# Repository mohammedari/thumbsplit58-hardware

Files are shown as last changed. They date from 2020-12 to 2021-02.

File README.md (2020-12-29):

# Thumbsplit58 Hardware
File archive for Thumbsplit58 keyboard PCB and case. You may also want to refer [Nordic MCU firmware](https://github.com/mohammedari/thumbsplit58-firmware) and [qmk_firmware](https://github.com/mohammedari/qmk_firmware/blob/oneoff/thumbsplit58/keyboards/thumbsplit58/) repository.

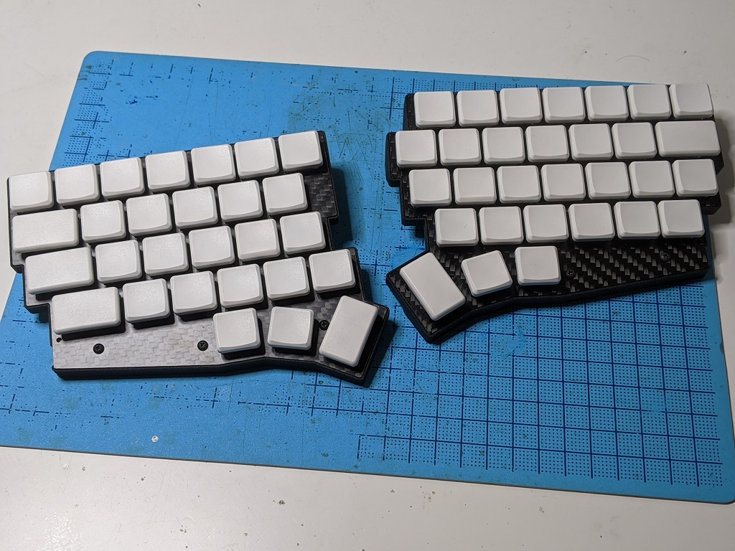
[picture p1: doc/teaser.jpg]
teaser


This repository only contains PCB gerber files for keyboard itself. 
You can use [Comet46's receiver gerber files](https://github.com/satt100/comet46-hardware.git) to make receiver for this keyboard.

## Top plates

Top plate DXF files are available under [dxf](dxf) directory.
This design is intended to be milled using 2mm endmill, 
but it should be manufacturable by laser cutters.

| | Left | Right |
| --- | --- | --- |
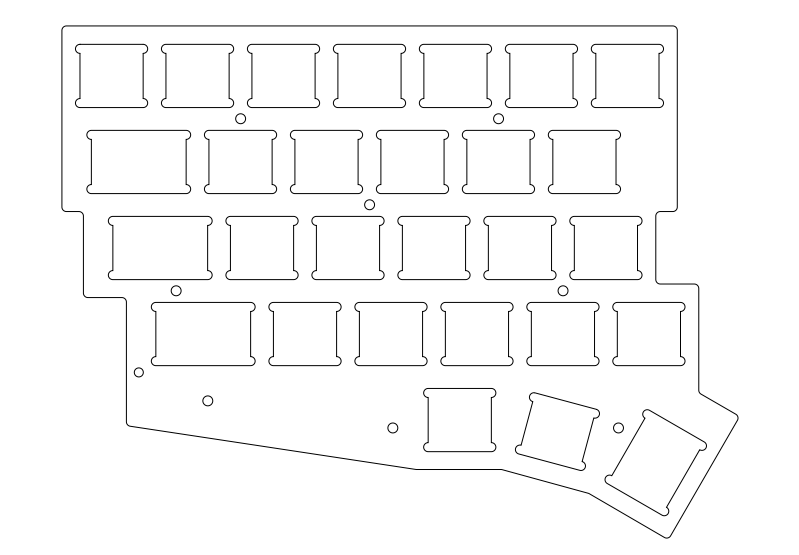
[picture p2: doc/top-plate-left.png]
left
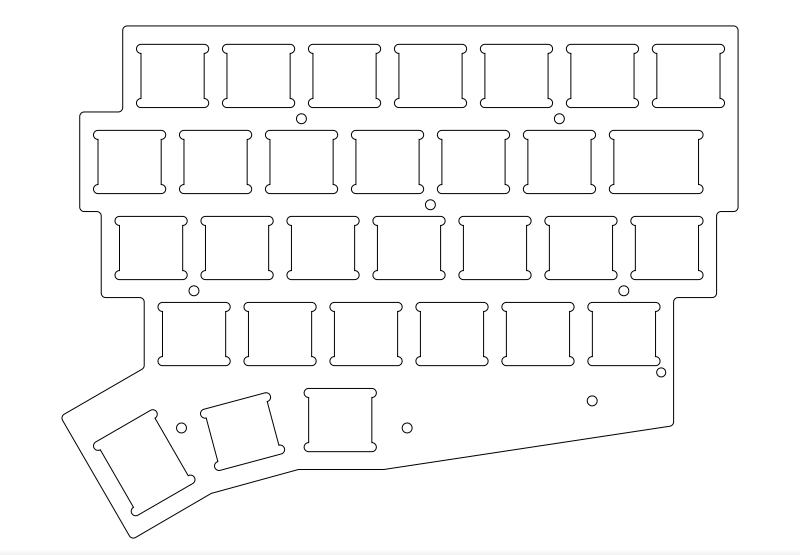
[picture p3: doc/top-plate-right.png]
right
| rev1 (1u/1.5u support) |  |  |
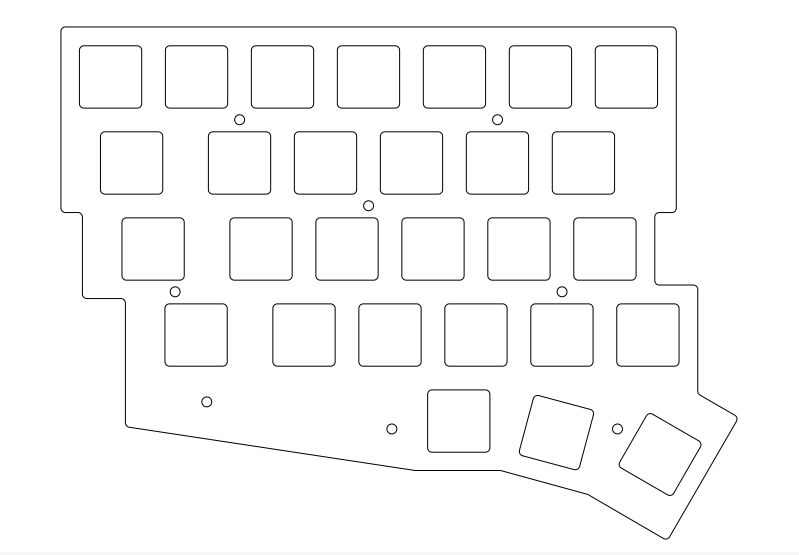
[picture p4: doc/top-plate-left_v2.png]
leftv2
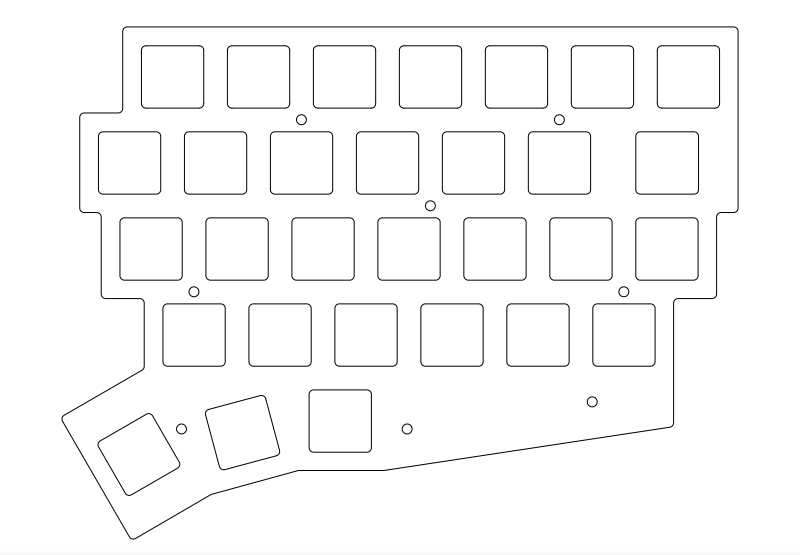
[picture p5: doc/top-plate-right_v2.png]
rightv2
| rev2 (1.5u only) |  |  |

## Case

Case STL files are available under [stl](stl) directory.
This design is intended to be 3D printed using SLS (Selective Laser Sintering) or SLA (Stereolithography) printer.
It may be printable by FDM (Fused Deposition Modeling) printers, but probably requires additional work.

| | Left | Right |
| --- | --- | --- |
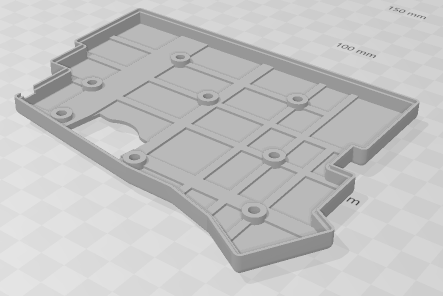
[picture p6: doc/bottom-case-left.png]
left
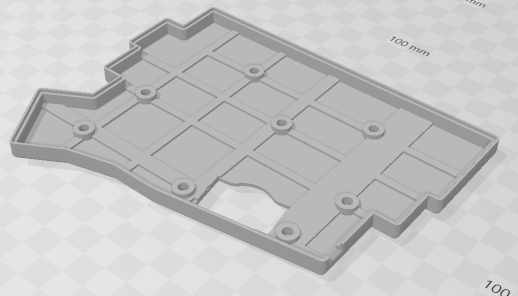
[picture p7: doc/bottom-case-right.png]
right
| rev1 (CR2032) |  |  |
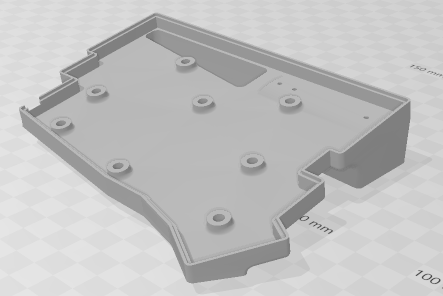
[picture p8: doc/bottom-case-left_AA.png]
leftAA
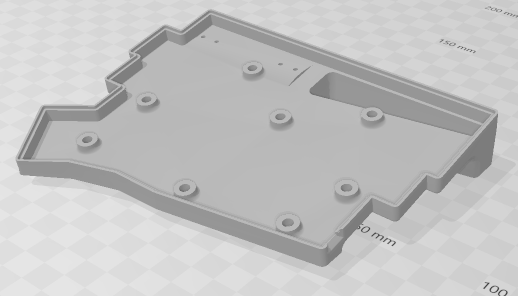
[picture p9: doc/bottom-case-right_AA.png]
rightAA
| rev2 (AA) |  |  |

## Gerber files

Gerber files are available under [gerber](gerber) directory. 
These archives follow Fusion PCB's design guideline and output instruction.

## Schematics

- [Right half](schematic/thumb-split-right-v1.0.pdf)
- [Left half](schematic/thumb-split-left-v1.0.pdf)

## Parts list

TODO

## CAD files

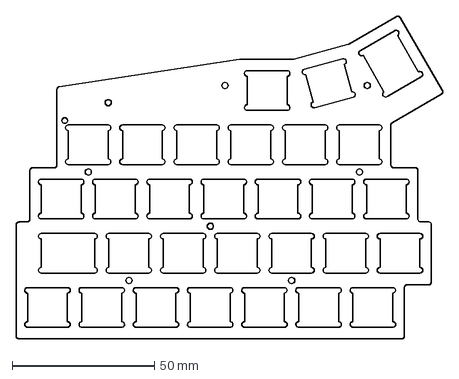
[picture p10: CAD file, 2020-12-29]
dxf/top-plate-right.dxf
149.8 x 113.4 mm

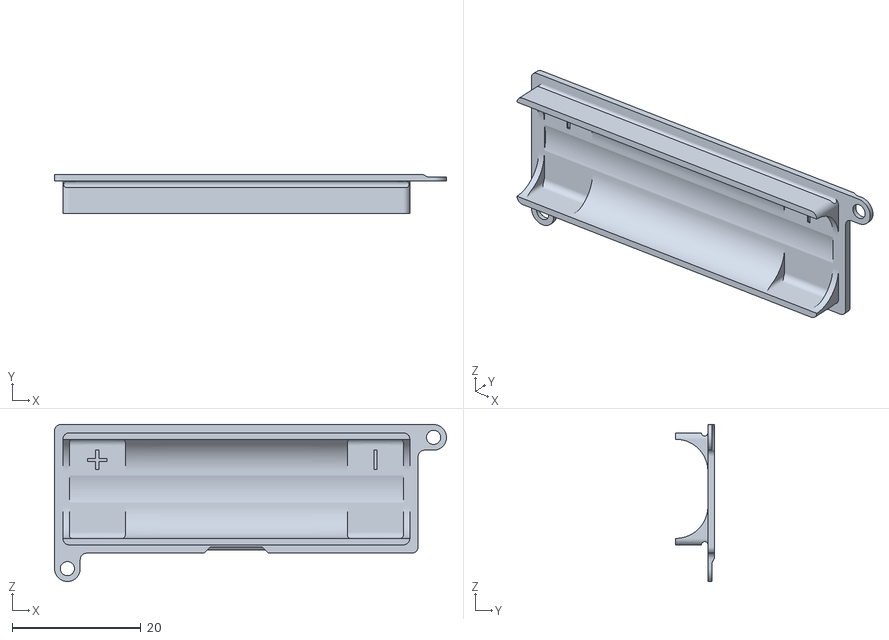
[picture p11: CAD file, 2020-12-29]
stl/battery-cover-right_v2.stl
60.9 x 6.00 x 24.4

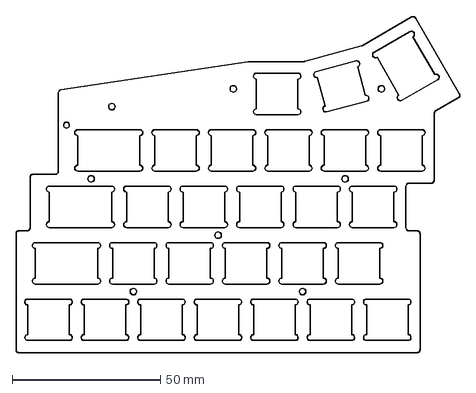
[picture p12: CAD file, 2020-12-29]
dxf/top-plate-left.dxf
149.8 x 113.4 mm

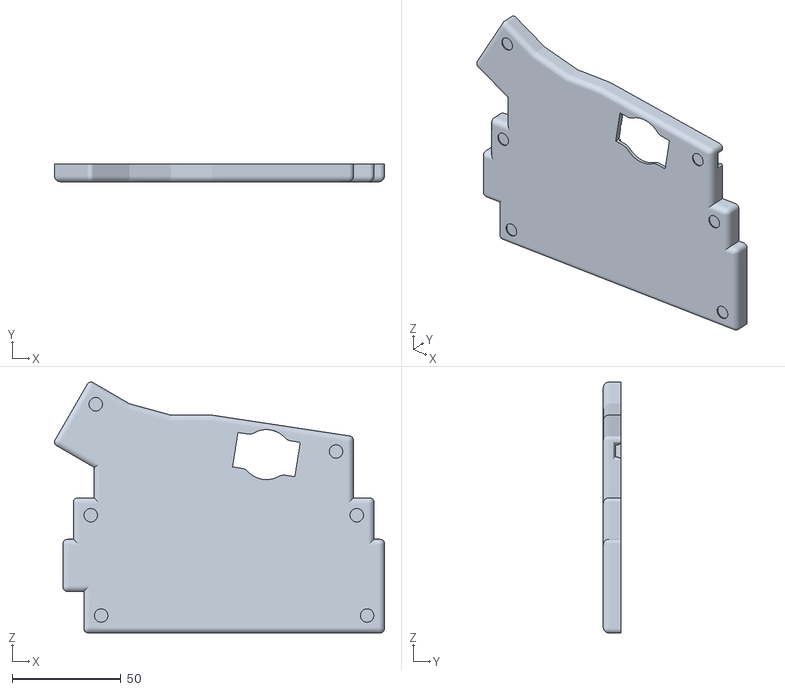
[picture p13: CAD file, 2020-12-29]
stl/bottom-case-right.stl
151.8 x 8.10 x 115.4

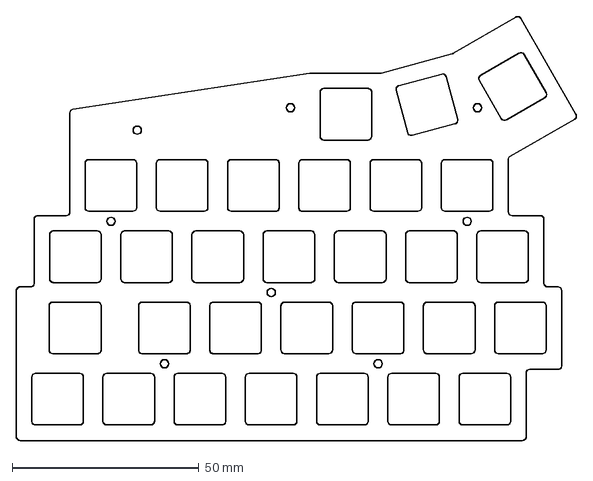
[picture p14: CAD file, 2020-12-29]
dxf/top-plate-right_v2.dxf
149.8 x 113.4 mm

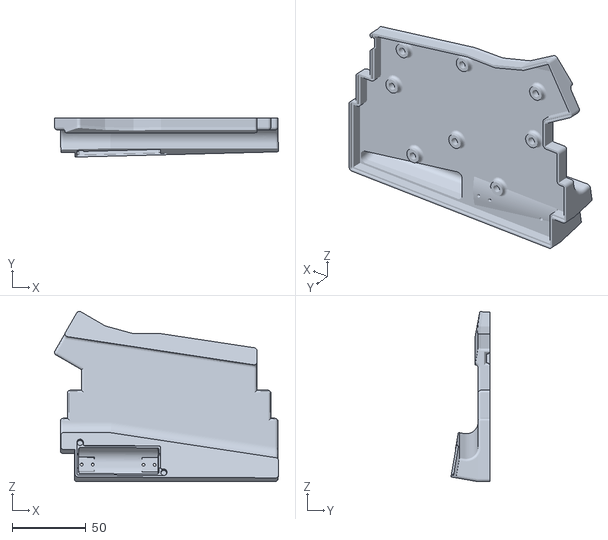
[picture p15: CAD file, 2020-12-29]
stl/bottom-case_AA-right.stl
152.2 x 26.5 x 115.7

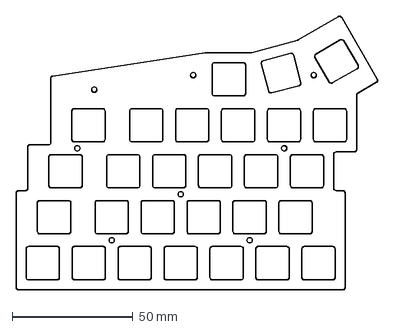
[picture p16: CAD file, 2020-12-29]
dxf/top-plate-left_v2.dxf
149.8 x 113.4 mm

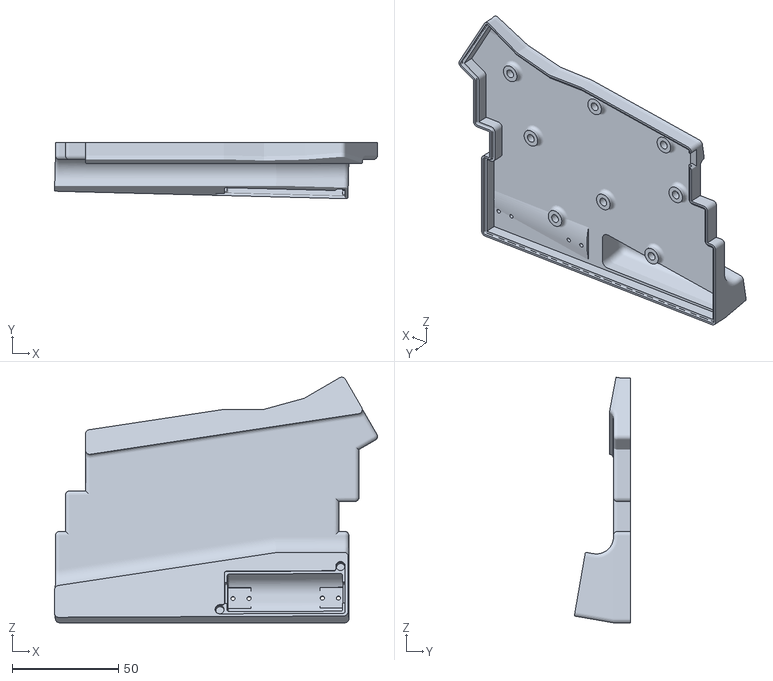
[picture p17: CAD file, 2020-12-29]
stl/bottom-case_AA-left.stl
152.2 x 26.5 x 115.7

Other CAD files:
stl/bottom-case-left.stl
stl/battery-cover-left_v2.stl

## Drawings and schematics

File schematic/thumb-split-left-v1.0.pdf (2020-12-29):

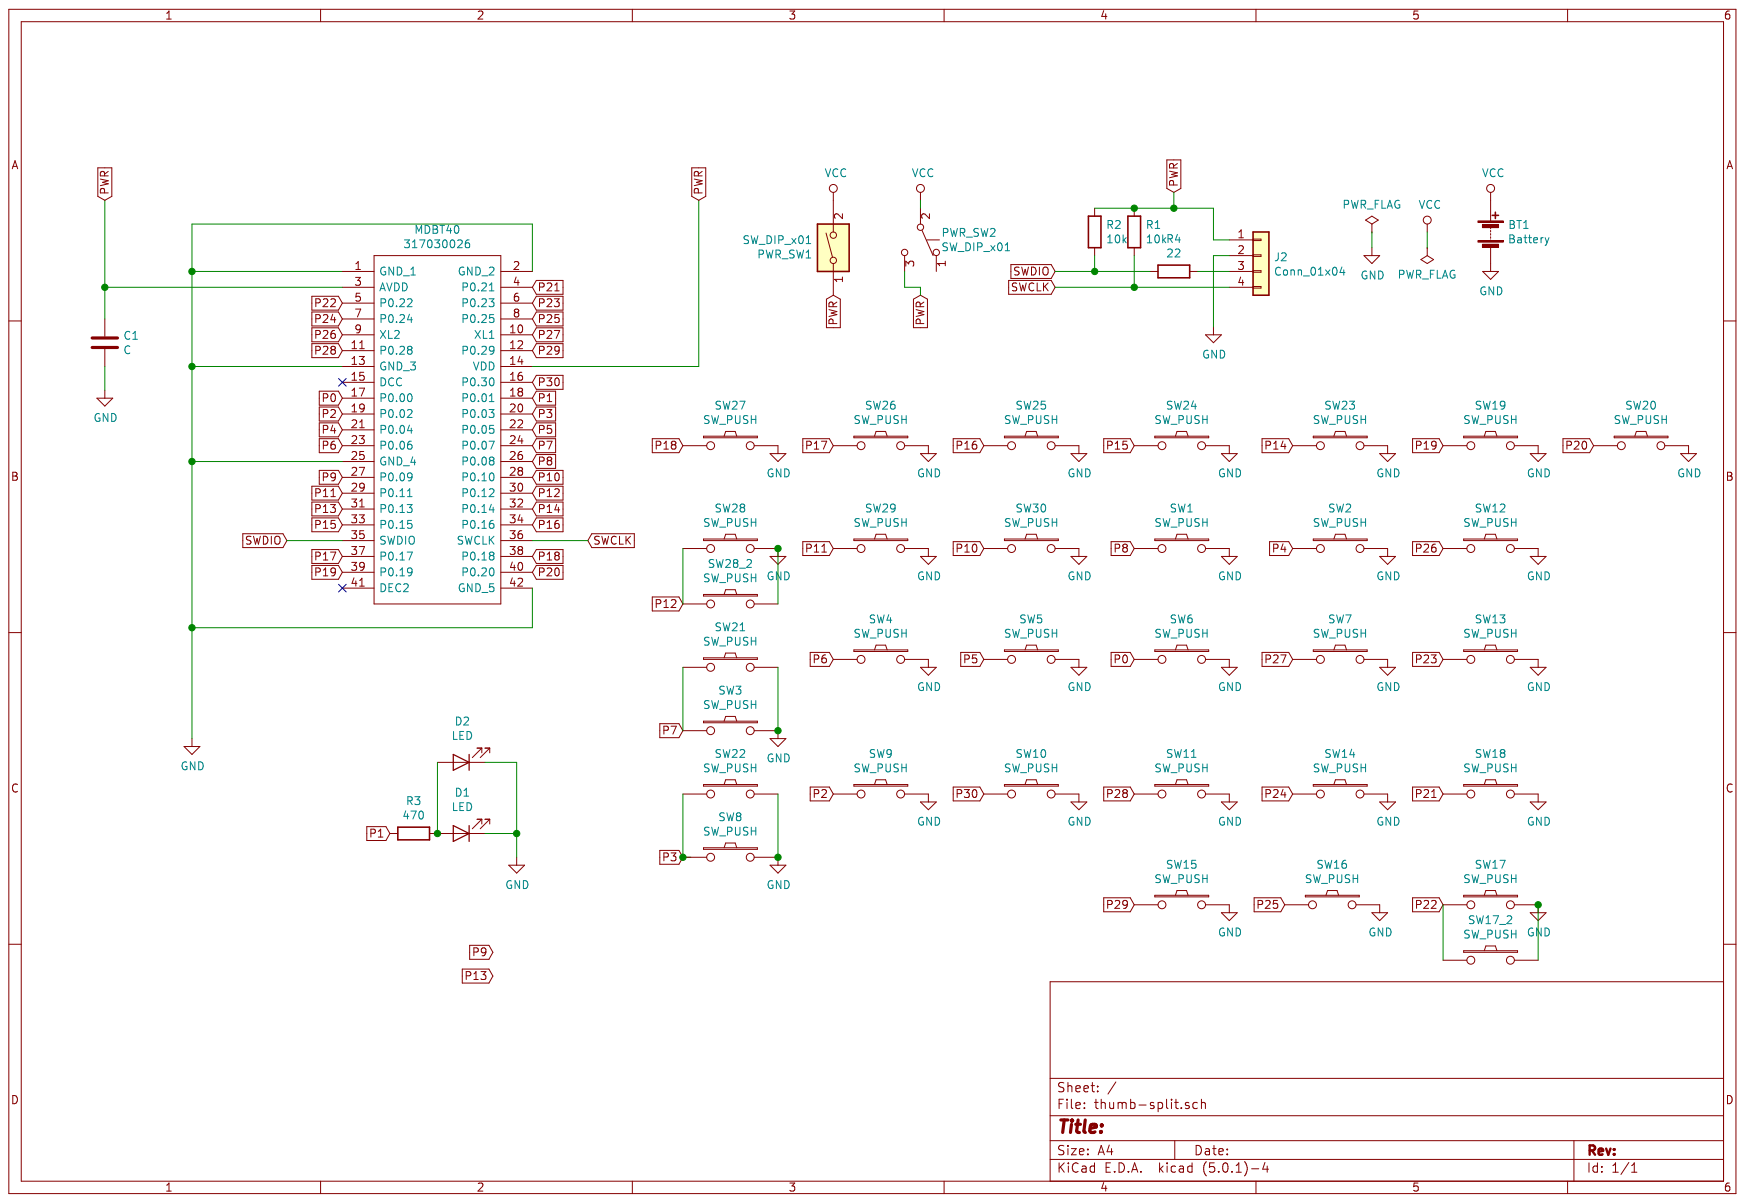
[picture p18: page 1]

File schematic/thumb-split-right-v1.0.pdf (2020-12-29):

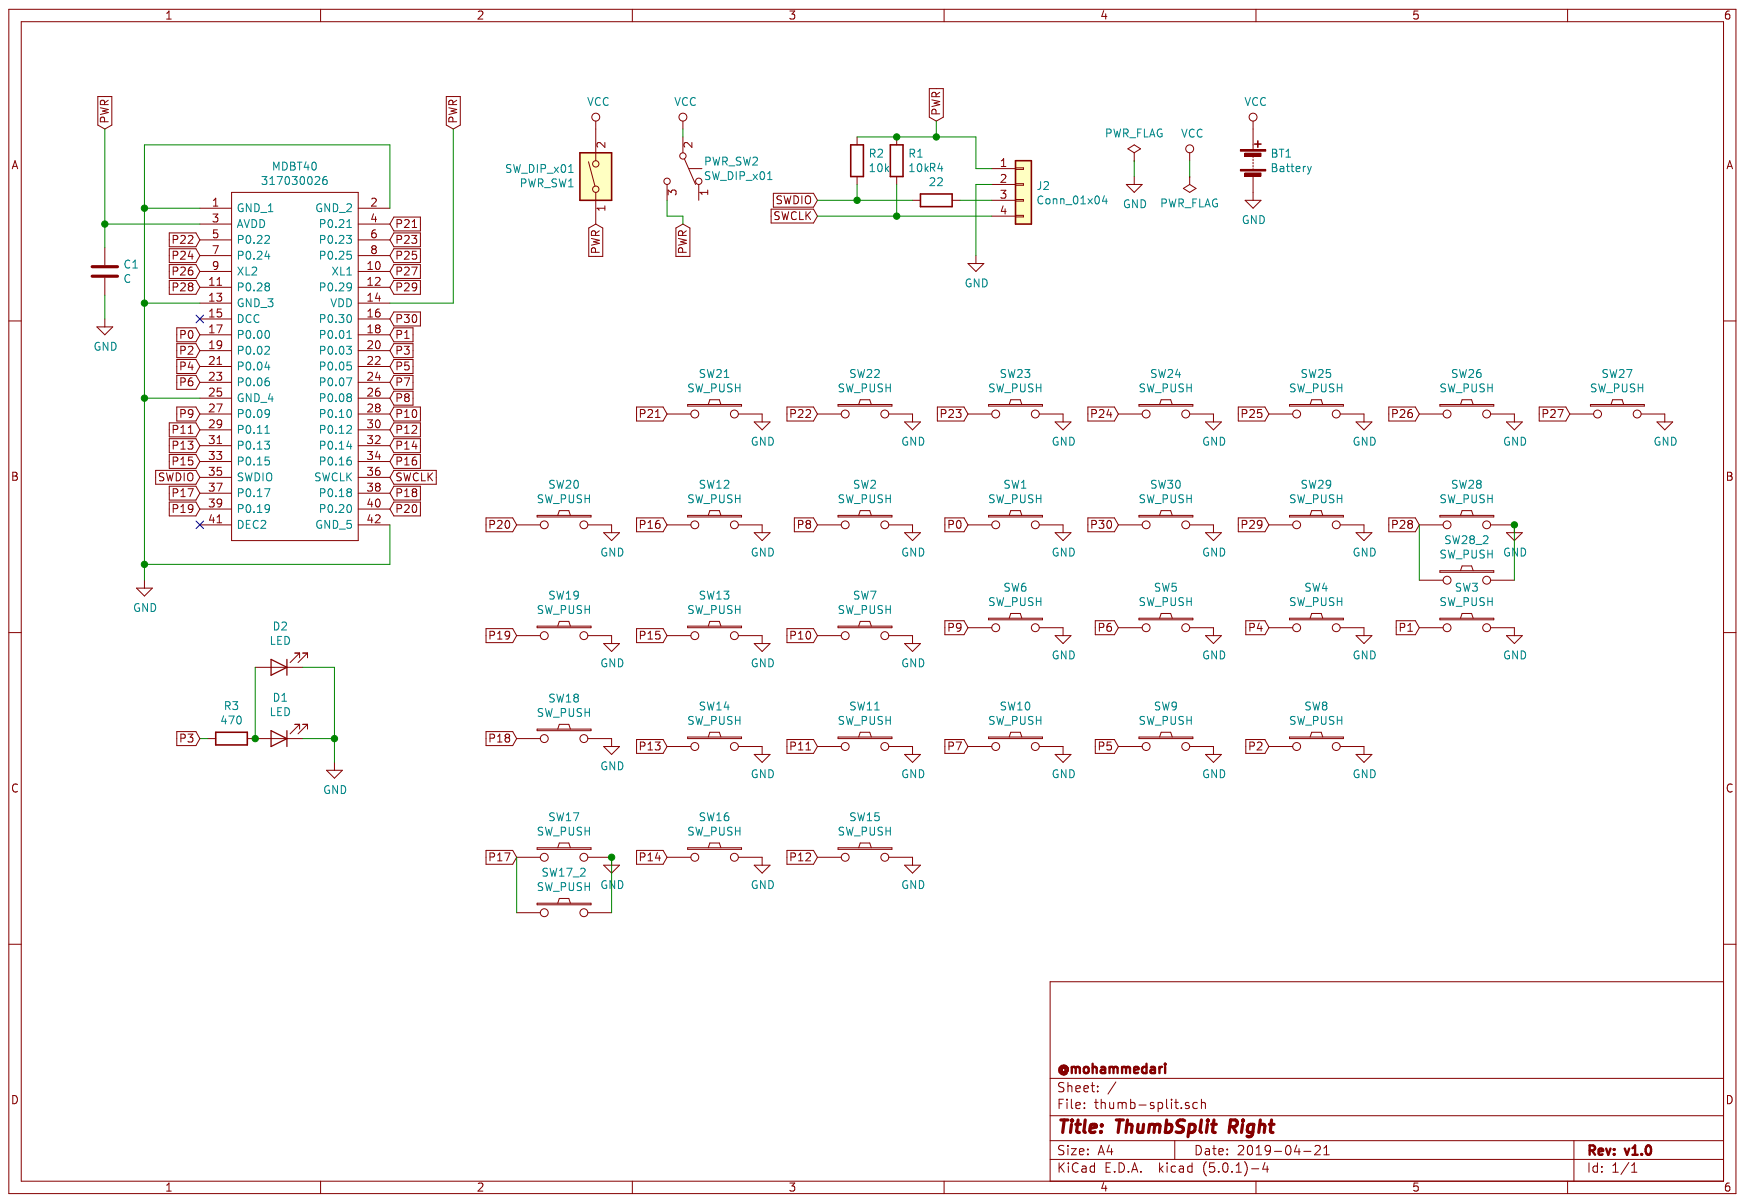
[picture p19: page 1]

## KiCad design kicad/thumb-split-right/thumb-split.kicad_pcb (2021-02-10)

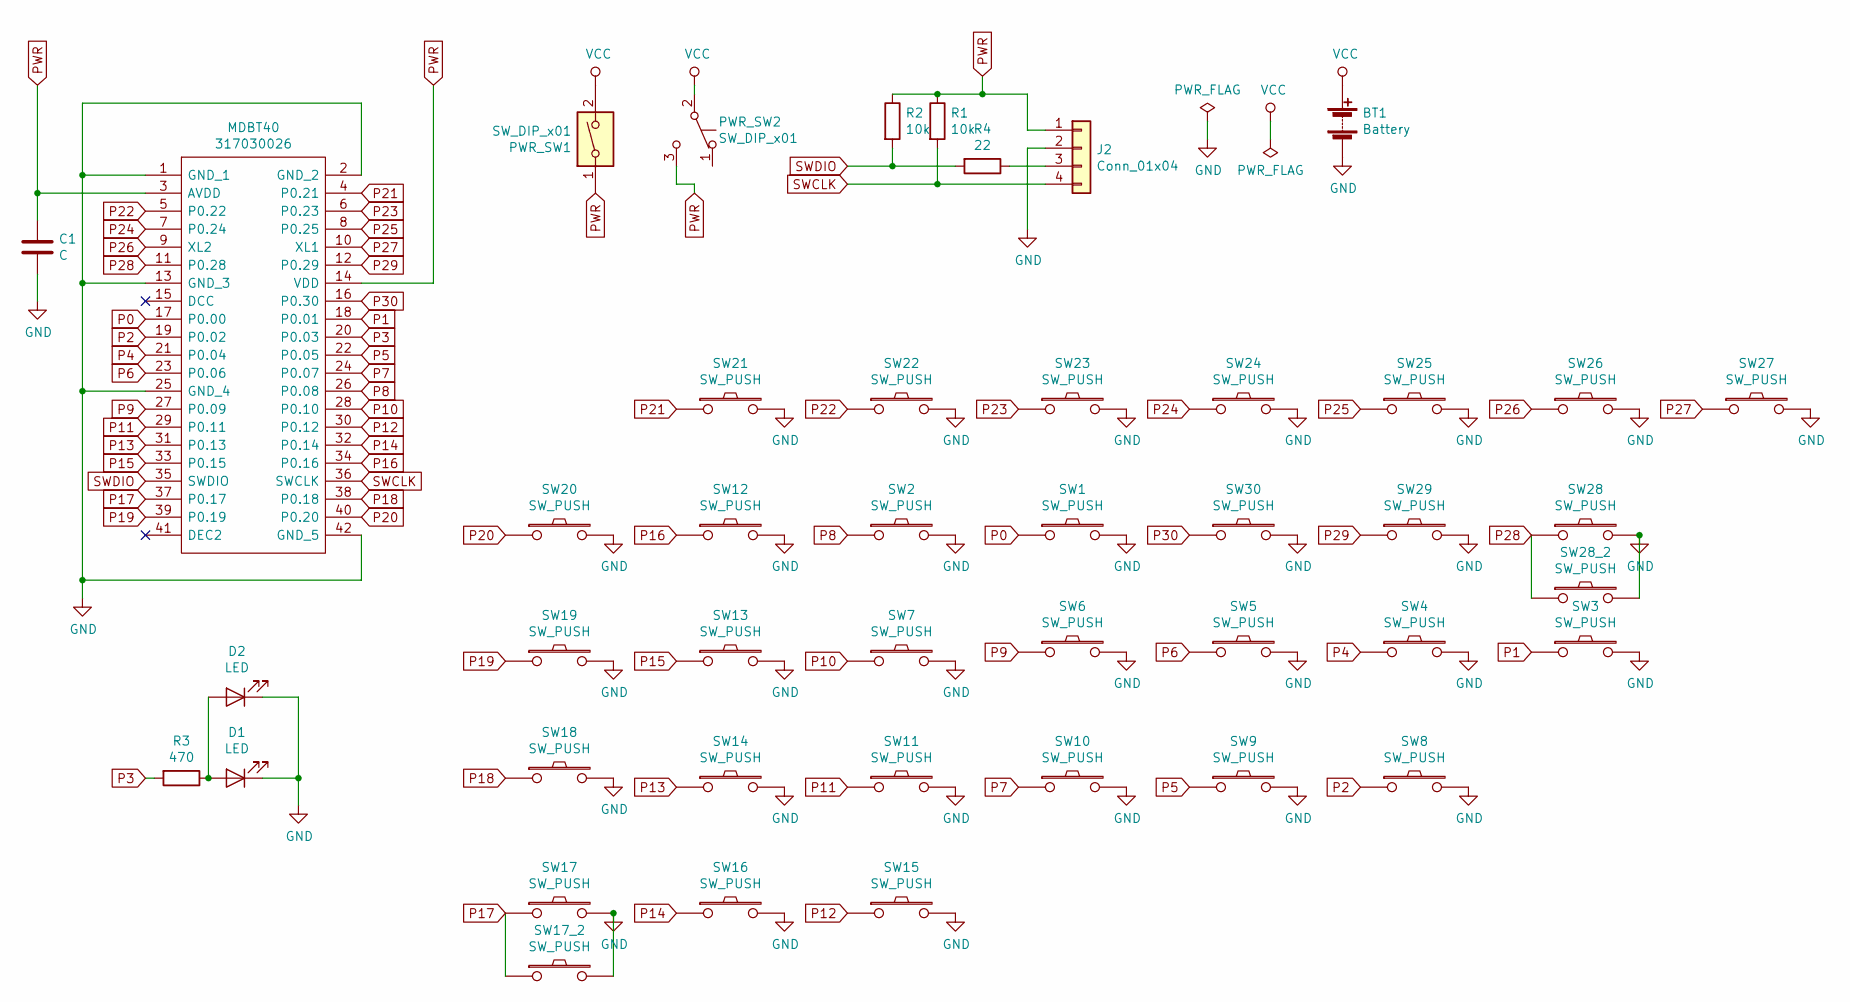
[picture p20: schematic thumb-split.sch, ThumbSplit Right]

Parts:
BT1: Battery; bhsd-2032
C1: C; C_0805_2012Metric_Pad1.15x1.40mm_HandSolder
D1, D2: LED; LED_0603_1608Metric_Pad1.05x0.95mm_HandSolder
J2: Conn_01x04; conn_throuth_01x04
MDBT40: 317030026; Manufacturer_Part_Number 317030026; Mouser Part Number 713-317030026
PWR_SW1, PWR_SW2: SW_DIP_x01; EG1257
R1, R2: 10k; R_0603_1608Metric_Pad1.05x0.95mm_HandSolder
R3: 470; R_0603_1608Metric_Pad1.05x0.95mm_HandSolder
R4: 22; R_0603_1608Metric_Pad1.05x0.95mm_HandSolder
SW1, SW2, SW3, SW4, SW5, SW6, SW7, SW8, SW9, SW10, SW11, SW12, SW13, SW14, SW15, SW16, SW17_2, SW18, SW19, SW20, SW21, SW22, SW23, SW24, SW25, SW26, SW27, SW28, SW28_2, SW29, SW30: SW_PUSH; Choc_Hotswap_1side
SW17: SW_PUSH; Choc_Hotswap_1side_1.5u

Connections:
GND: BT1.2 (-), C1.2, D1.1 (K), D2.1 (K), J2.2, MDBT40.1 (GND_1), MDBT40.2 (GND_2), MDBT40.13 (GND_3), MDBT40.25 (GND_4), MDBT40.42 (GND_5), SW1.2, SW2.2, SW3.2, SW4.2, SW5.2, SW6.2, SW7.2, SW8.2, SW9.2, SW10.2, SW11.2, SW12.2, SW13.2, SW14.2, SW15.2, SW16.2, SW17.2, SW17_2.2, SW18.2, SW19.2, SW20.2, SW21.2, SW22.2, SW23.2, SW24.2, SW25.2, SW26.2, SW27.2, SW28.2, SW28_2.2, SW29.2, SW30.2
unnamed: D1.2 (A), D2.2 (A), R3.1
unnamed: J2.3, R4.1
P0: MDBT40.17 (P0.00), SW1.1
P1: MDBT40.18 (P0.01), SW3.1
P2: MDBT40.19 (P0.02), SW8.1
P3: MDBT40.20 (P0.03), R3.2
P4: MDBT40.21 (P0.04), SW4.1
P5: MDBT40.22 (P0.05), SW9.1
P6: MDBT40.23 (P0.06), SW5.1
P7: MDBT40.24 (P0.07), SW10.1
P8: MDBT40.26 (P0.08), SW2.1
P9: MDBT40.27 (P0.09), SW6.1
P10: MDBT40.28 (P0.10), SW7.1
P11: MDBT40.29 (P0.11), SW11.1
P12: MDBT40.30 (P0.12), SW15.1
P13: MDBT40.31 (P0.13), SW14.1
P14: MDBT40.32 (P0.14), SW16.1
P15: MDBT40.33 (P0.15), SW13.1
P16: MDBT40.34 (P0.16), SW12.1
P17: MDBT40.37 (P0.17), SW17.1, SW17_2.1
P18: MDBT40.38 (P0.18), SW18.1
P19: MDBT40.39 (P0.19), SW19.1
P20: MDBT40.40 (P0.20), SW20.1
P21: MDBT40.4 (P0.21), SW21.1
P22: MDBT40.5 (P0.22), SW22.1
P23: MDBT40.6 (P0.23), SW23.1
P24: MDBT40.7 (P0.24), SW24.1
P25: MDBT40.8 (P0.25), SW25.1
P26: MDBT40.9 (XL2), SW26.1
P27: MDBT40.10 (XL1), SW27.1
P28: MDBT40.11 (P0.28), SW28.1, SW28_2.1
P29: MDBT40.12 (P0.29), SW29.1
P30: MDBT40.16 (P0.30), SW30.1
PWR: C1.1, J2.1, MDBT40.3 (AVDD), MDBT40.14 (VDD), PWR_SW1.1, PWR_SW2.3 (C), R1.1, R2.1
SWCLK: J2.4, MDBT40.36 (SWCLK), R1.2
SWDIO: MDBT40.35 (SWDIO), R2.2, R4.2
VCC: BT1.1 (+), PWR_SW1.2, PWR_SW2.2 (B)

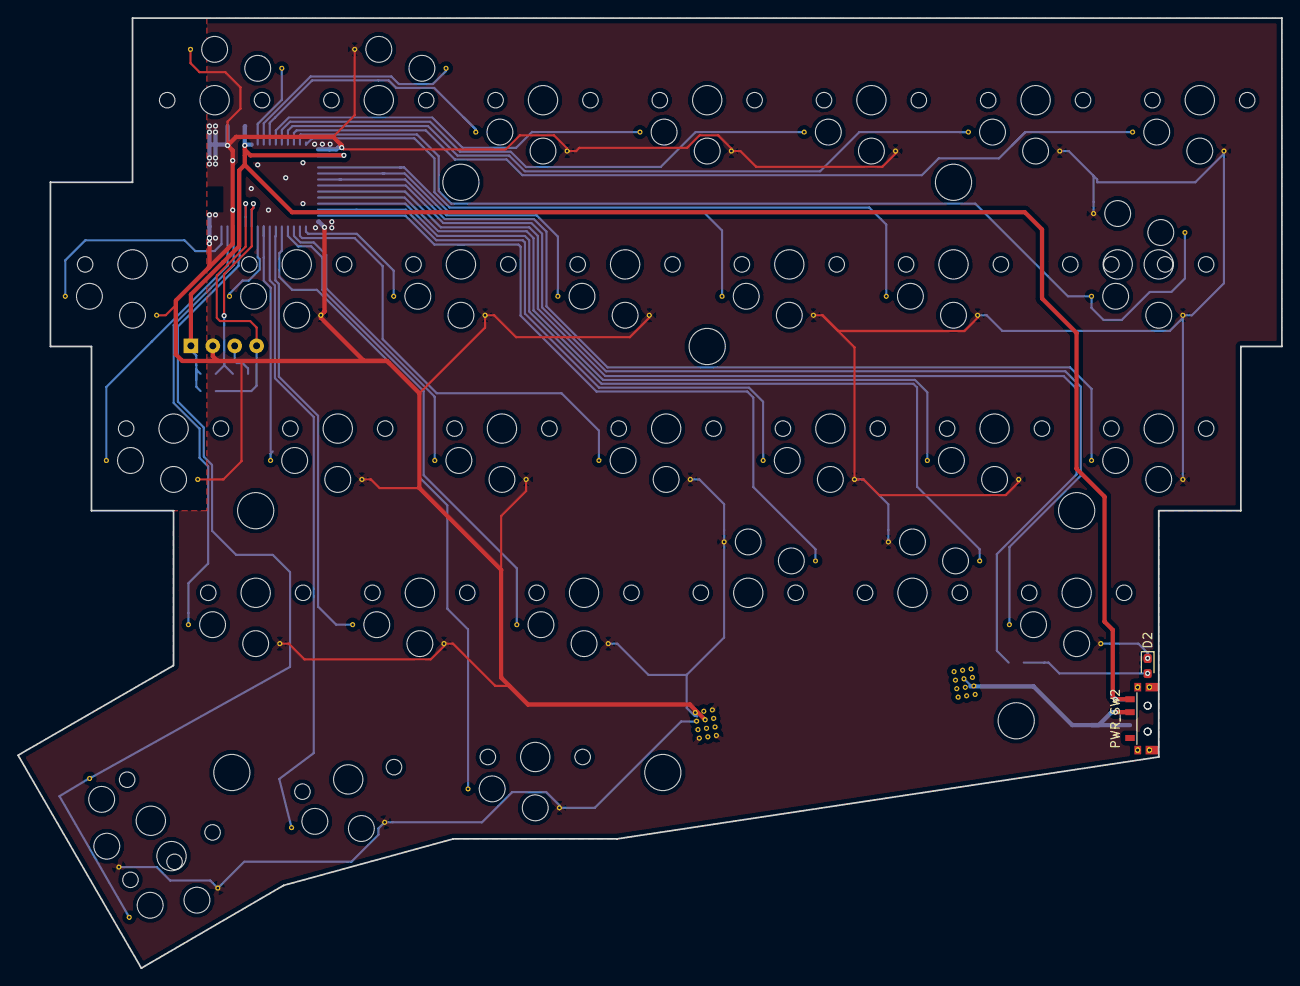
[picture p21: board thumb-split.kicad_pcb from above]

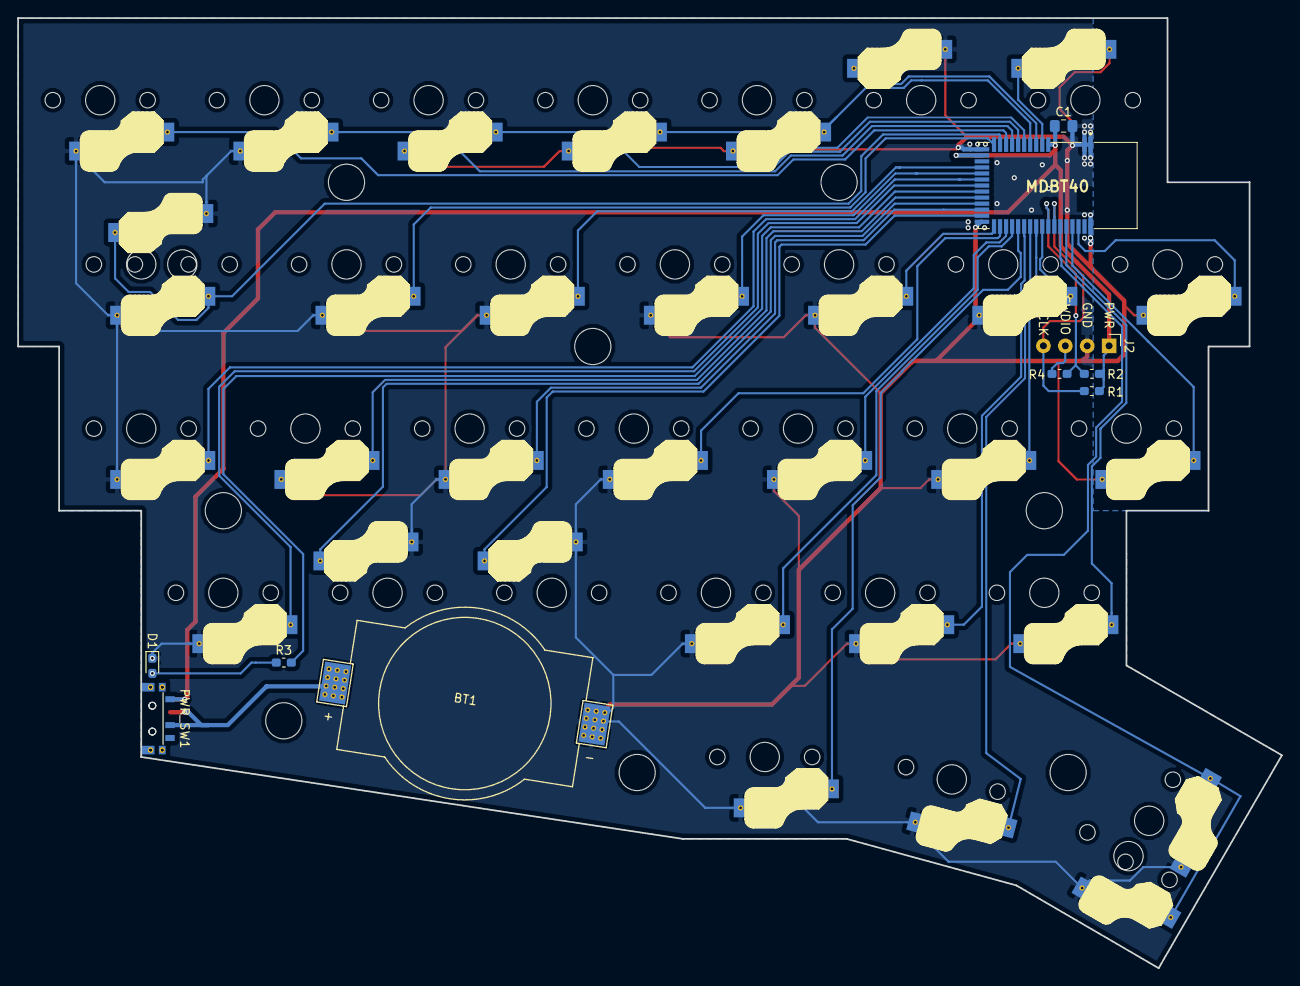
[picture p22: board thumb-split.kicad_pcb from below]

Board: 2 copper layers, 146.6 x 110.2 mm, 44 parts (10 on the bottom side), 38 nets.
